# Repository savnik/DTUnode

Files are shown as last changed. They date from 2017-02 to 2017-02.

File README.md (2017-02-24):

DTUnodeMCU
==============

A DTU version of NodeMCU using ESP8285 instead of ESP8266. ESP8285 has built-in flash memory which ESP8266 does not. Besides that the ESP8285 is very much the same.
This will be send to PCB production in March 2017 and tested afterwards.

## Features

- ESP8285, 26 MHz resonator
- Built-in flash memory
- Built-in Wi-Fi
- Onboard PCB Antenna
- Reset and flash button
- Input voltage from 1.3v to 6 volts
- Diode protection for battery and USB power supply
- JST battery connector
- Built-in battery voltage measurement
- RGB Led
- RFM95 LoRaWAN module
- HDC1010 High Accuracy humidity sensor
- VEML6030 High Accuracy Ambient Light Sensor
- MAG3110 Three axis digital magnetometer
- DS3231 Real time clock
- BMP280 Digital pressure sensor
- Pin headers for FTDI, I2C, Chip enable and 2 GPIO's

- - - - - -
Author Peter Savnik
Supervisor Ali Ozkil

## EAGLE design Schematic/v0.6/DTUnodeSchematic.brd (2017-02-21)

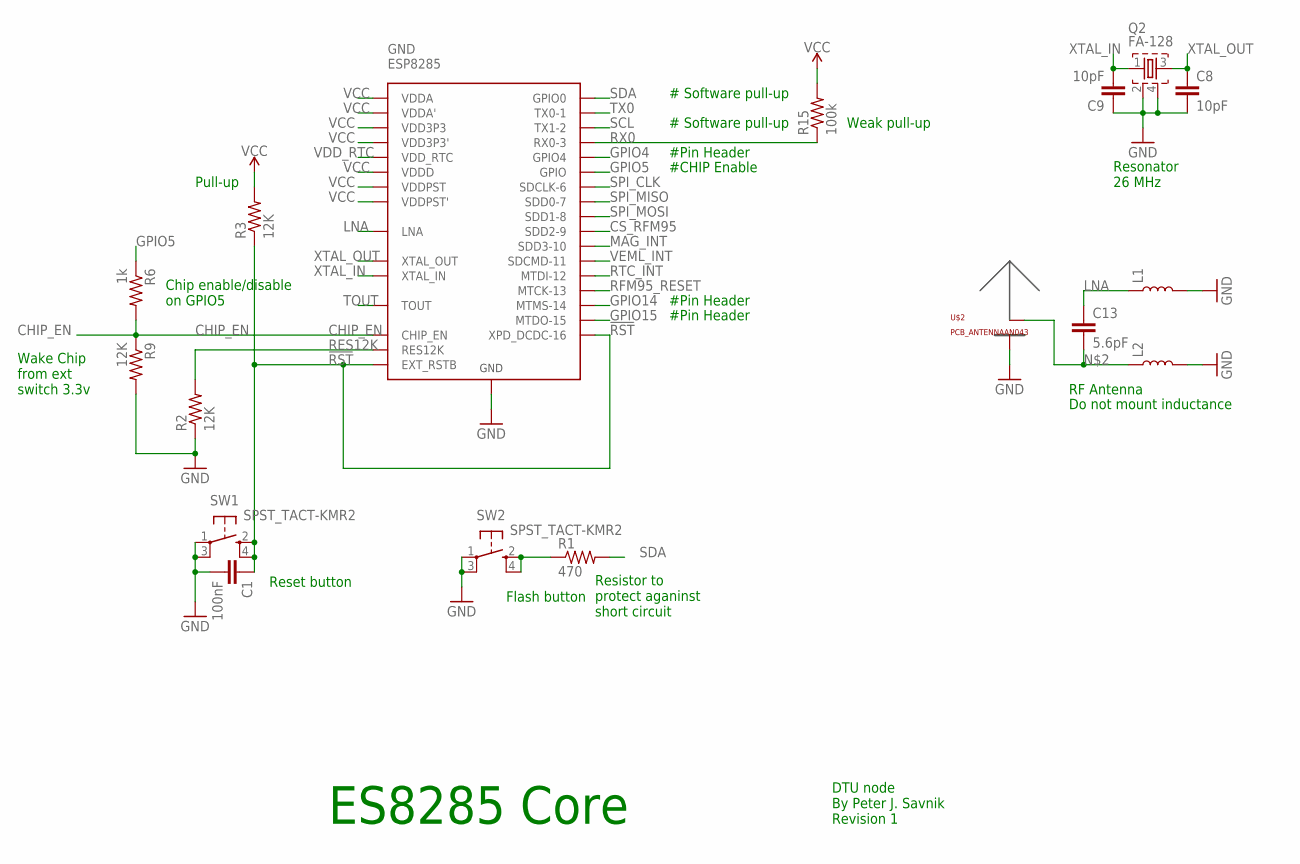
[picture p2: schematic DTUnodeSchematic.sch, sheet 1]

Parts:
C1: 100nF; C0402K
C8, C9: 10pF; C0402K
C13: 5.6pF; C0402K
GND: ESP8285; QFN-32
L1, L2: INDUCTOR-0402-3.9NH; 0402
Q2: FA-128
R1: 470; R0402
R2, R3, R9: 12K; R0402
R6: 1k; R0402
R15: 100k; R0402
SW1, SW2: SPST_TACT-KMR2; KMR2
U$2: PCB_ANTENNAAN043; PCB_ANTENNA_TI-AN043

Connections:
!RST: C1.1, GND.P$8 (XPD_DCDC-16), GND.P$32 (EXT_RSTB), R3.1, SW1.2 (S), SW1.4 (S1); also elsewhere on the board
CHIP_EN: GND.P$7 (CHIP_EN), R6.2, R9.1; also elsewhere on the board
CS_RFM95: GND.P$18 (SDD2-9); also elsewhere on the board
GND: C1.2, C8.2, C9.1, GND.33-GND (GND), L1.2, L2.2, Q2.2, Q2.4, R2.1, R9.2, SW1.1, SW1.3 (P1), SW2.1, SW2.3 (P1), U$2.GND; also elsewhere on the board
GPIO4: GND.P$16 (GPIO4); also elsewhere on the board
GPIO5: GND.P$24 (GPIO), R6.1
GPIO14: GND.P$9 (MTMS-14); also elsewhere on the board
GPIO15: GND.P$13 (MTDO-15); also elsewhere on the board
LNA: C13.1, GND.P$2 (LNA), L1.1
MAG_INT: GND.P$19 (SDD3-10); also elsewhere on the board
unnamed: R1.1, SW2.2 (S), SW2.4 (S1)
unnamed: C13.2, L2.1, U$2.ANT (AND)
RES12K: GND.P$31 (RES12K), R2.2
RFM95_RESET: GND.P$12 (MTCK-13); also elsewhere on the board
RTC_INT: GND.P$10 (MTDI-12); also elsewhere on the board
RX0: GND.P$25 (RX0-3), R15.1; also elsewhere on the board
SCL: GND.P$14 (TX1-2); also elsewhere on the board
SDA: GND.P$15 (GPIO0), R1.2; also elsewhere on the board
SPI_CLK: GND.P$21 (SDCLK-6); also elsewhere on the board
SPI_MISO: GND.P$22 (SDD0-7); also elsewhere on the board
SPI_MOSI: GND.P$23 (SDD1-8); also elsewhere on the board
TOUT: GND.P$6 (TOUT); also elsewhere on the board
TX0: GND.P$26 (TX0-1); also elsewhere on the board
VCC: GND.P$1 (VDDA), GND.P$3 (VDD3P3), GND.P$4 (VDD3P3'), GND.P$11 (VDDPST), GND.P$17 (VDDPST'), GND.P$29 (VDDD), GND.P$30 (VDDA'), R3.2, R15.2; also elsewhere on the board
VDD_RTC: GND.P$5 (VDD_RTC)
VEML_INT: GND.P$20 (SDCMD-11); also elsewhere on the board
XTAL_IN: C9.2, GND.P$28 (XTAL_IN), Q2.1
XTAL_OUT: C8.1, GND.P$27 (XTAL_OUT), Q2.3

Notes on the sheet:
Resonator 26 MHz
Chip enable/disable on GPIO5
RF Antenna
Do not mount inductance
DTU node By Peter J. Savnik Revision 1
ES8285 Core
Reset button
Flash button
Resistor to protect aganinst short circuit
#Pin Header
#CHIP Enable
Wake Chip from ext switch 3.3v
# Software pull-up
Weak pull-up
Pull-up

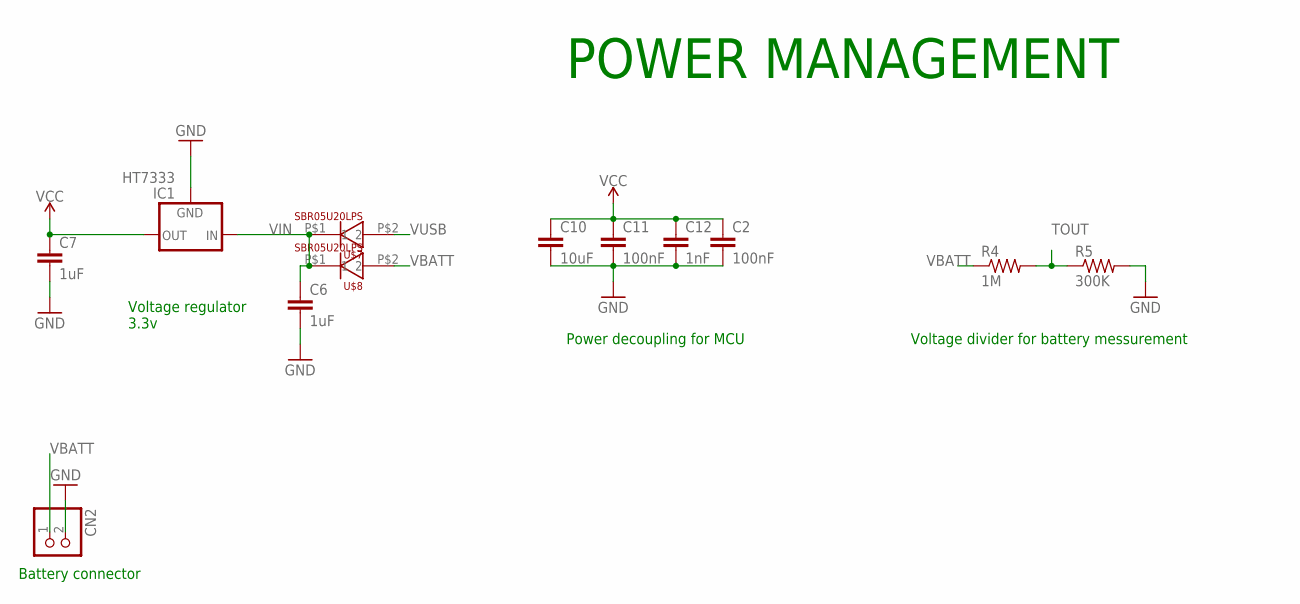
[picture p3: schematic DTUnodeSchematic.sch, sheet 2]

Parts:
C2, C11: 100nF; C0402K
C6, C7: 1uF; C0402K
C10: 10uF; C0402K
C12: 1nF; C0402K
CN2: JST_2PIN-THM-RA; JST-PH-2-THM-RA
IC1: HT7333; SOT-89
R4: 1M; R0402
R5: 300K; R0402
U$7, U$8: SBR05U20LPS; X2-DFN1006-2

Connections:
GND: C2.2, C6.2, C7.2, C10.2, C11.2, C12.2, CN2.2 (1), IC1.2 (GND), R5.2; also elsewhere on the board
TOUT: R4.2, R5.1; also elsewhere on the board
VBATT: CN2.1 (2), R4.1, U$8.P$2 (1); also elsewhere on the board
VCC: C2.1, C7.1, C10.1, C11.1, C12.1, IC1.1 (OUT); also elsewhere on the board
VIN: C6.1, IC1.3 (IN), IC1.4 (IN), U$7.P$1 (2), U$8.P$1 (2)
VUSB: U$7.P$2 (1); also elsewhere on the board

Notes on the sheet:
Voltage regulator 3.3v
POWER MANAGEMENT
Battery connector
Power decoupling for MCU
Voltage divider for battery messurement

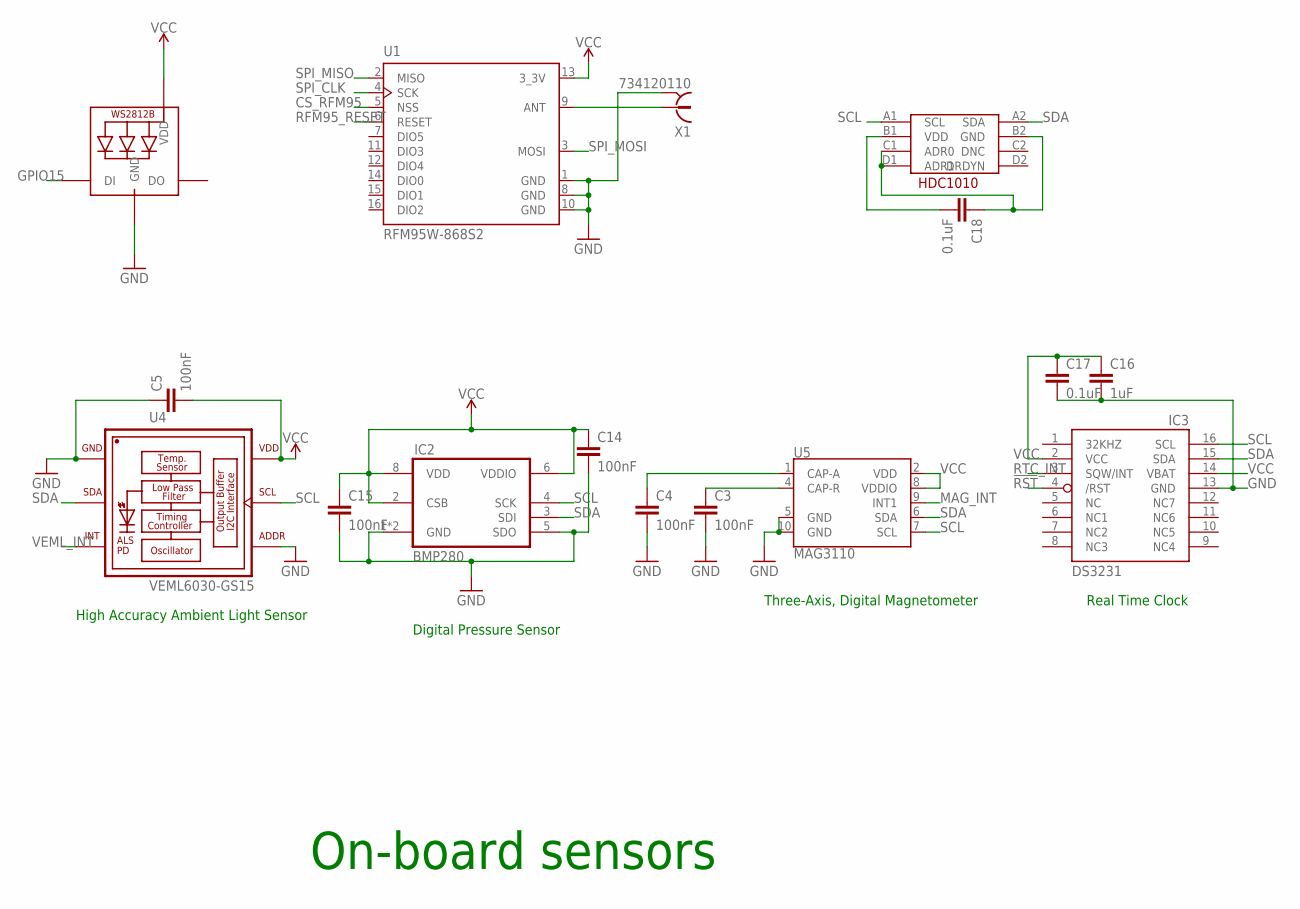
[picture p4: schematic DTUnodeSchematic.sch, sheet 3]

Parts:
C3, C4, C5, C14, C15: 100nF; C0402
C16: 1uF; C0402
C17, C18: 0.1uF; C0402
IC2: BMP280
IC3: DS3231/SO; SO16W
LED1: WS2812B5050; WS2812B
U1: RFM95W-868S2; XCVR_RFM95W-868S2
U4: VEML6030-GS15; VISHAY_VEML6030_2X2X0.87
U5: MAG3110; DFN-10
U$3: HDC1010; DSBGA-8
X1: 734120110

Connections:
!RST: IC3.4 (/RST); also elsewhere on the board
CS_RFM95: U1.5 (NSS); also elsewhere on the board
GND: C3.2, C4.2, C5.1, C14.2, C15.2, C16.2, C17.2, IC2.1 (GND), IC2.5 (SDO), IC2.7 (GND), IC3.13 (GND), LED1.3-GND (GND), U1.1 (GND), U1.8 (GND), U1.10 (GND), U4.1 (GND), U4.4 (ADDR), U5.5 (GND), U5.10 (GND), X1.S@1 (2), X1.S@2 (2), X1.S@3 (2); also elsewhere on the board
GPIO15: LED1.4-DIN (DI); also elsewhere on the board
MAG_INT: U5.9 (INT1); also elsewhere on the board
unnamed: U1.9 (ANT), X1.1
unnamed: C18.2, U$3.B1 (VDD)
unnamed: C18.1, U$3.B2 (GND), U$3.C1 (ADR0), U$3.D1 (ADR1)
unnamed: C3.1, U5.4 (CAP-R)
unnamed: C4.1, U5.1 (CAP-A)
RFM95_RESET: U1.6 (RESET); also elsewhere on the board
RTC_INT: IC3.3 (SQW/INT); also elsewhere on the board
SCL: IC2.4 (SCK), IC3.16 (SCL), U4.5 (SCL), U5.7 (SCL), U$3.A1 (SCL); also elsewhere on the board
SDA: IC2.3 (SDI), IC3.15 (SDA), U4.2 (SDA), U5.6 (SDA), U$3.A2 (SDA); also elsewhere on the board
SPI_CLK: U1.4 (SCK); also elsewhere on the board
SPI_MISO: U1.2 (MISO); also elsewhere on the board
SPI_MOSI: U1.3 (MOSI); also elsewhere on the board
VCC: C5.2, C14.1, C15.1, C16.1, C17.1, IC2.2 (CSB), IC2.6 (VDDIO), IC2.8 (VDD), IC3.2 (VCC), IC3.14 (VBAT), LED1.1-VDD (VDD), U1.13 (3_3V), U4.6 (VDD), U5.2 (VDD), U5.8 (VDDIO); also elsewhere on the board
VEML_INT: U4.3 (INT); also elsewhere on the board

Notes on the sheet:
On-board sensors
High Accuracy Ambient Light Sensor
Digital Pressure Sensor
Real Time Clock
Three-Axis, Digital Magnetometer

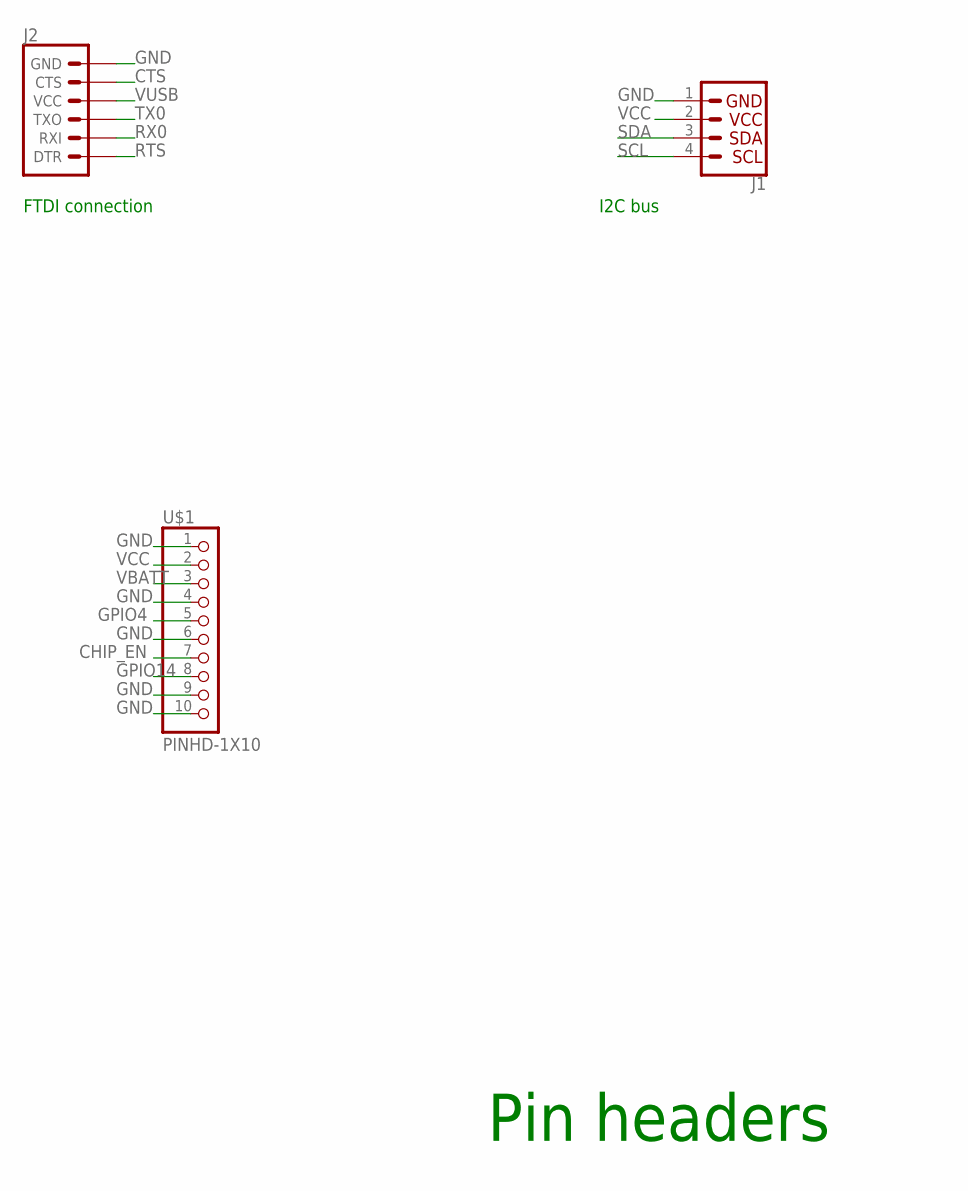
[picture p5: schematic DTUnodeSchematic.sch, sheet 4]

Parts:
J1: I2C_STANDARD; 1X04
J2: 6_PIN_SERIAL_TARGET; 1X06
U$1: PINHD-1X10; 1X10-BIG

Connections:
CHIP_EN: U$1.7; also elsewhere on the board
CTS: J2.5 (CTS)
GND: J1.1, J2.6 (GND), U$1.1, U$1.4, U$1.6, U$1.9, U$1.10; also elsewhere on the board
GPIO4: U$1.5; also elsewhere on the board
GPIO14: U$1.8; also elsewhere on the board
RTS: J2.1 (DTR)
RX0: J2.2 (RXI); also elsewhere on the board
SCL: J1.4; also elsewhere on the board
SDA: J1.3; also elsewhere on the board
TX0: J2.3 (TXO); also elsewhere on the board
VBATT: U$1.3; also elsewhere on the board
VCC: J1.2, U$1.2; also elsewhere on the board
VUSB: J2.4 (VCC); also elsewhere on the board

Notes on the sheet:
FTDI connection
Pin headers
I2C bus

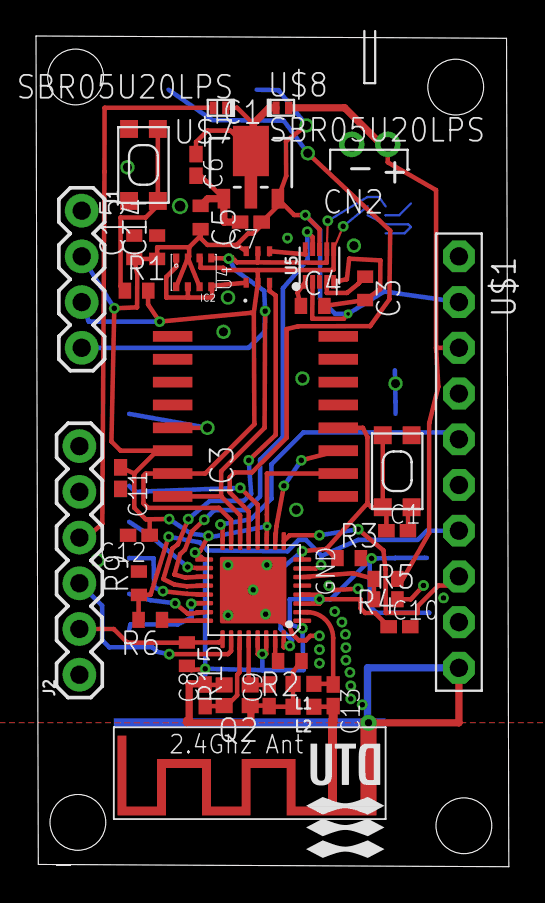
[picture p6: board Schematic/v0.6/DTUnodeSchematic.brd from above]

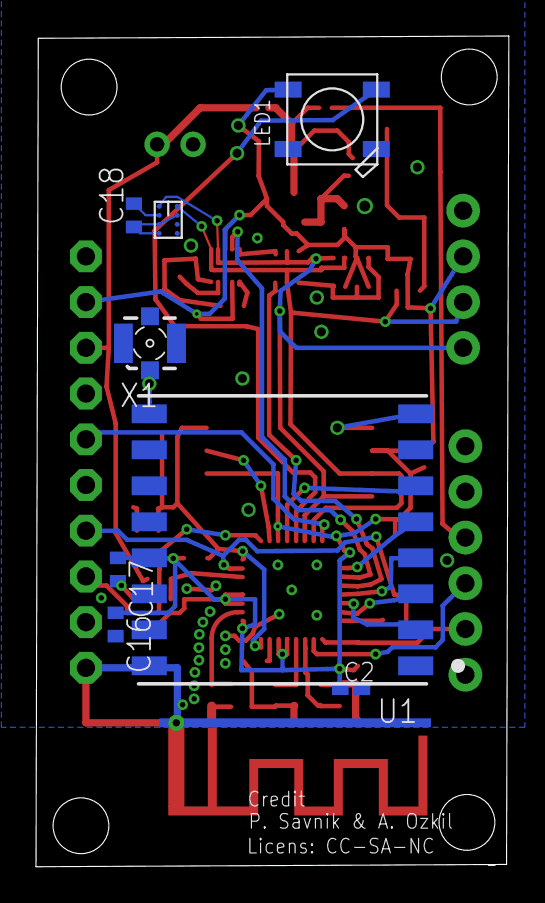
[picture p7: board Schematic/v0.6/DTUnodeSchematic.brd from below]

Board: 2 copper layers, 26.3 x 46.2 mm, 48 parts (8 on the bottom side), 35 nets.

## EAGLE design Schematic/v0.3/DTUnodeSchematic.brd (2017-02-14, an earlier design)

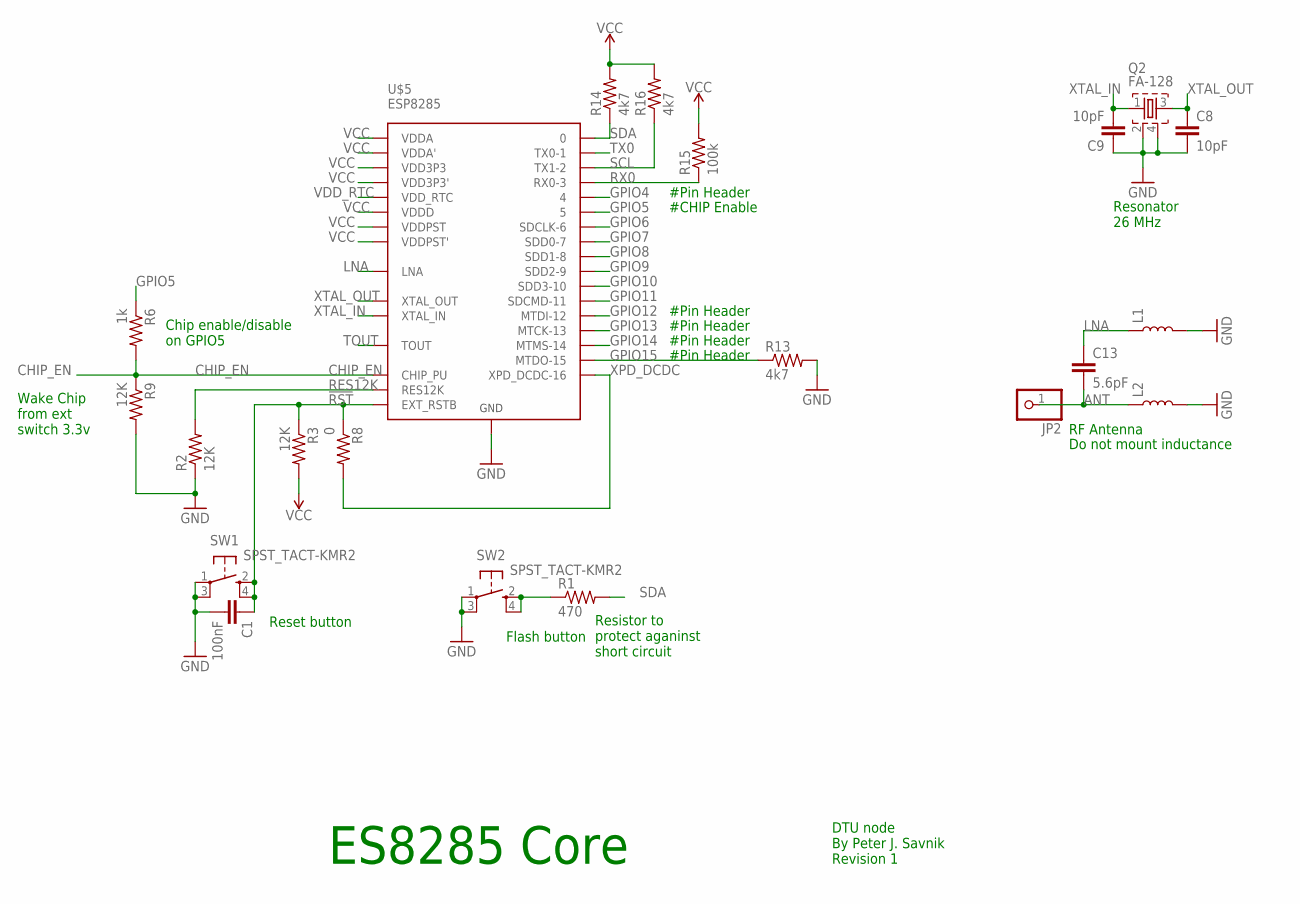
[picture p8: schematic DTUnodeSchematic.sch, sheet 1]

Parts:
C1: 100nF; C0402K
C8, C9: 10pF; C0402K
C13: 5.6pF; C0402K
JP2: PINHD-1X1; 1X01
L1, L2: INDUCTOR-0402-3.9NH; 0402
Q2: FA-128
R1: 470; R0402
R2, R3, R9: 12K; R0402
R6: 1k; R0402
R8: 0; R0402
R13, R14, R16: 4k7; R0402
R15: 100k; R0402
SW1, SW2: SPST_TACT-KMR2; KMR2
U$5: ESP8285; QFN-32

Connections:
!RST: C1.1, R3.1, R8.1, SW1.2 (S), SW1.4 (S1), U$5.P$32 (EXT_RSTB)
ANT: C13.2, JP2.1, L2.1
CHIP_EN: R6.2, R9.1, U$5.P$7 (CHIP_PU); also elsewhere on the board
GND: C1.2, C8.2, C9.1, L1.2, L2.2, Q2.2, Q2.4, R2.1, R9.2, R13.2, SW1.1, SW1.3 (P1), SW2.1, SW2.3 (P1), U$5.33-GND (GND); also elsewhere on the board
GPIO4: U$5.P$16 (4); also elsewhere on the board
GPIO5: R6.1, U$5.P$24 (5)
GPIO6: U$5.P$21 (SDCLK-6)
GPIO7: U$5.P$22 (SDD0-7)
GPIO8: U$5.P$23 (SDD1-8)
GPIO9: U$5.P$18 (SDD2-9)
GPIO10: U$5.P$19 (SDD3-10)
GPIO11: U$5.P$20 (SDCMD-11)
GPIO12: U$5.P$10 (MTDI-12); also elsewhere on the board
GPIO13: U$5.P$12 (MTCK-13); also elsewhere on the board
GPIO14: U$5.P$9 (MTMS-14); also elsewhere on the board
GPIO15: R13.1, U$5.P$13 (MTDO-15); also elsewhere on the board
LNA: C13.1, L1.1, U$5.P$2 (LNA)
unnamed: R1.1, SW2.2 (S), SW2.4 (S1)
RES12K: R2.2, U$5.P$31 (RES12K)
RX0: R15.1, U$5.P$25 (RX0-3); also elsewhere on the board
SCL: R16.1, U$5.P$14 (TX1-2); also elsewhere on the board
SDA: R1.2, R14.1, U$5.P$15 (0); also elsewhere on the board
TOUT: U$5.P$6 (TOUT); also elsewhere on the board
TX0: U$5.P$26 (TX0-1); also elsewhere on the board
VCC: R3.2, R14.2, R15.2, R16.2, U$5.P$1 (VDDA), U$5.P$3 (VDD3P3), U$5.P$4 (VDD3P3'), U$5.P$11 (VDDPST), U$5.P$17 (VDDPST'), U$5.P$29 (VDDD), U$5.P$30 (VDDA'); also elsewhere on the board
VDD_RTC: U$5.P$5 (VDD_RTC)
XPD_DCDC: R8.2, U$5.P$8 (XPD_DCDC-16)
XTAL_IN: C9.2, Q2.1, U$5.P$28 (XTAL_IN)
XTAL_OUT: C8.1, Q2.3, U$5.P$27 (XTAL_OUT)

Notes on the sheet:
Resonator 26 MHz
Chip enable/disable on GPIO5
RF Antenna
Do not mount inductance
DTU node By Peter J. Savnik Revision 1
ES8285 Core
Reset button
Flash button
Resistor to protect aganinst short circuit
#Pin Header
#CHIP Enable
Wake Chip from ext switch 3.3v

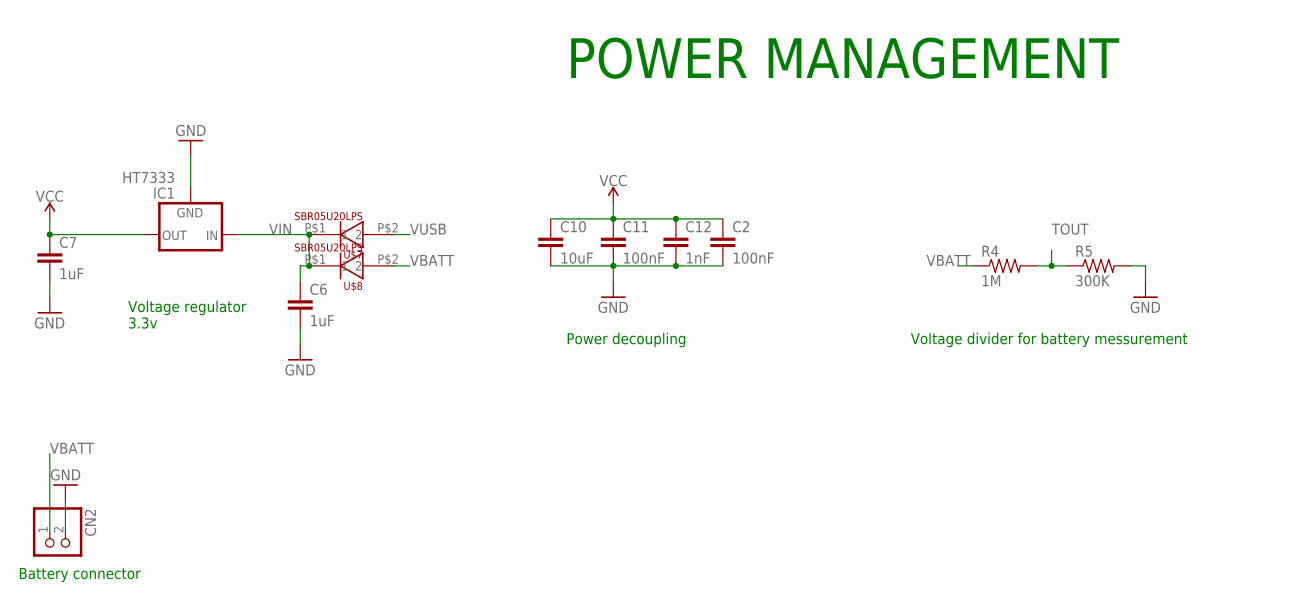
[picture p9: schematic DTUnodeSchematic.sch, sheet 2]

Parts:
C2, C11: 100nF; C0402K
C6, C7: 1uF; C0402K
C10: 10uF; C0402K
C12: 1nF; C0402K
CN2: JST_2PIN-THM-RA; JST-PH-2-THM-RA
IC1: HT7333; SOT-89
R4: 1M; R0402
R5: 300K; R0402
U$7, U$8: SBR05U20LPS; X2-DFN1006-2

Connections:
GND: C2.2, C6.2, C7.2, C10.2, C11.2, C12.2, CN2.2 (1), IC1.2 (GND), R5.2; also elsewhere on the board
TOUT: R4.2, R5.1; also elsewhere on the board
VBATT: CN2.1 (2), R4.1, U$8.P$2 (1); also elsewhere on the board
VCC: C2.1, C7.1, C10.1, C11.1, C12.1, IC1.1 (OUT); also elsewhere on the board
VIN: C6.1, IC1.3 (IN), IC1.4 (IN), U$7.P$1 (2), U$8.P$1 (2)
VUSB: U$7.P$2 (1); also elsewhere on the board

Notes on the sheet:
Voltage regulator 3.3v
POWER MANAGEMENT
Battery connector
Power decoupling
Voltage divider for battery messurement

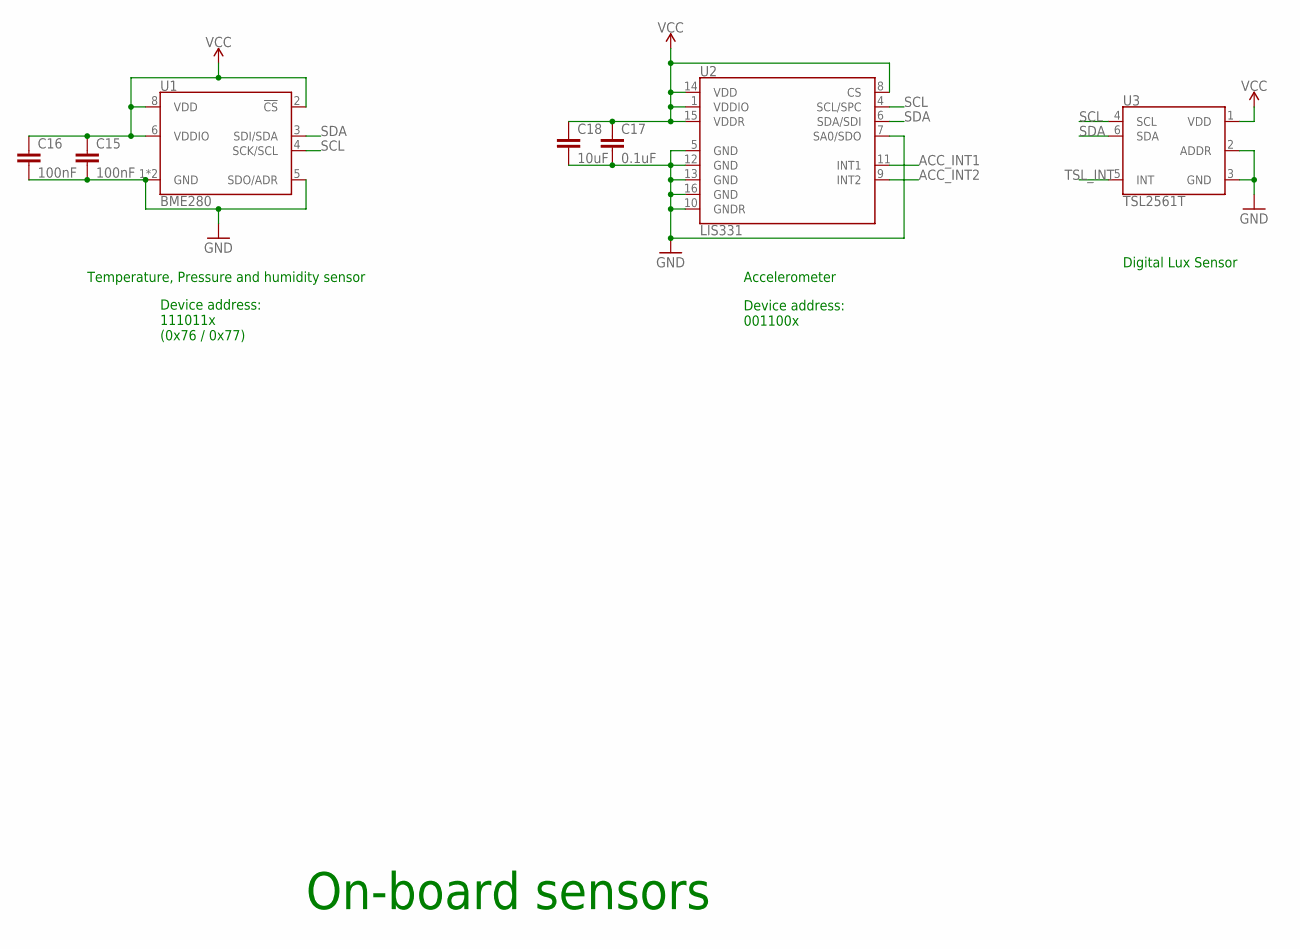
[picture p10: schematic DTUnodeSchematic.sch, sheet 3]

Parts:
C15, C16: 100nF; C0402
C17: 0.1uF; C0402
C18: 10uF; C0402
U1: BME280; LGA-8-2.5X2.5
U2: LIS331; LGA-16-3X3
U3: TSL2561T; TMB-6

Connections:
ACC_INT1: U2.11 (INT1)
ACC_INT2: U2.9 (INT2)
GND: C15.2, C16.2, C17.2, C18.2, U1.1 (GND), U1.5 (SDO/ADR), U1.7 (GND), U2.5 (GND), U2.7 (SA0/SDO), U2.10 (GNDR), U2.12 (GND), U2.13 (GND), U2.16 (GND), U3.2 (ADDR), U3.3 (GND); also elsewhere on the board
SCL: U1.4 (SCK/SCL), U2.4 (SCL/SPC), U3.4 (SCL); also elsewhere on the board
SDA: U1.3 (SDI/SDA), U2.6 (SDA/SDI), U3.6 (SDA); also elsewhere on the board
TSL_INT: U3.5 (INT)
VCC: C15.1, C16.1, C17.1, C18.1, U1.2 (!CS), U1.6 (VDDIO), U1.8 (VDD), U2.1 (VDDIO), U2.8 (CS), U2.14 (VDD), U2.15 (VDDR), U3.1 (VDD); also elsewhere on the board

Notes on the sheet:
Temperature, Pressure and humidity sensor
Device address: 111011x (0x76 / 0x77)
Device address: 001100x
Accelerometer
Digital Lux Sensor
On-board sensors

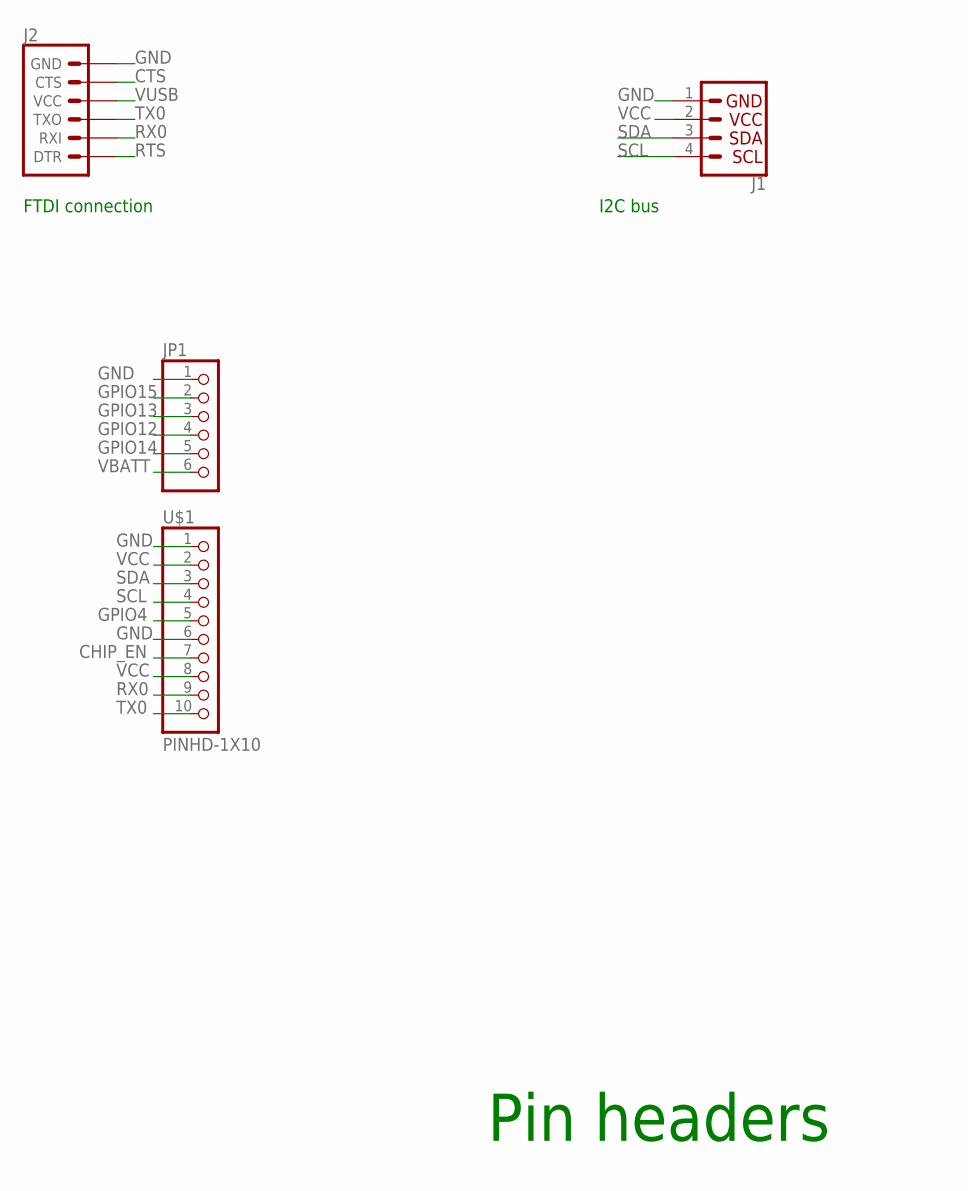
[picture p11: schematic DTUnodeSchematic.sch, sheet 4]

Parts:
J1: I2C_STANDARD; 1X04
J2: 6_PIN_SERIAL_TARGET; 1X06
JP1: PINHD-1X6; 1X06
U$1: PINHD-1X10; 1X10-BIG

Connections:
CHIP_EN: U$1.7; also elsewhere on the board
CTS: J2.5 (CTS)
GND: J1.1, J2.6 (GND), JP1.1, U$1.1, U$1.6; also elsewhere on the board
GPIO4: U$1.5; also elsewhere on the board
GPIO12: JP1.4; also elsewhere on the board
GPIO13: JP1.3; also elsewhere on the board
GPIO14: JP1.5; also elsewhere on the board
GPIO15: JP1.2; also elsewhere on the board
RTS: J2.1 (DTR)
RX0: J2.2 (RXI), U$1.9; also elsewhere on the board
SCL: J1.4, U$1.4; also elsewhere on the board
SDA: J1.3, U$1.3; also elsewhere on the board
TX0: J2.3 (TXO), U$1.10; also elsewhere on the board
VBATT: JP1.6; also elsewhere on the board
VCC: J1.2, U$1.2, U$1.8; also elsewhere on the board
VUSB: J2.4 (VCC); also elsewhere on the board

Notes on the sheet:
FTDI connection
Pin headers
I2C bus

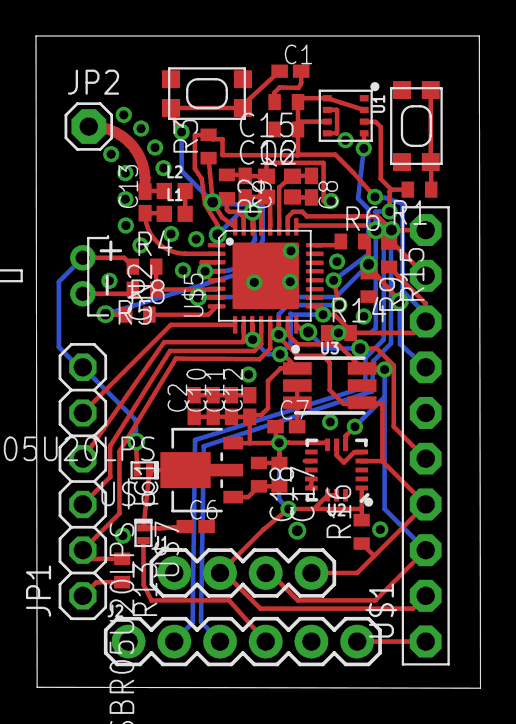
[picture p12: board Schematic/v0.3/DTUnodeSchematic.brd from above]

Board: 2 copper layers, 24.7 x 36.2 mm, 44 parts (0 on the bottom side), 25 nets.

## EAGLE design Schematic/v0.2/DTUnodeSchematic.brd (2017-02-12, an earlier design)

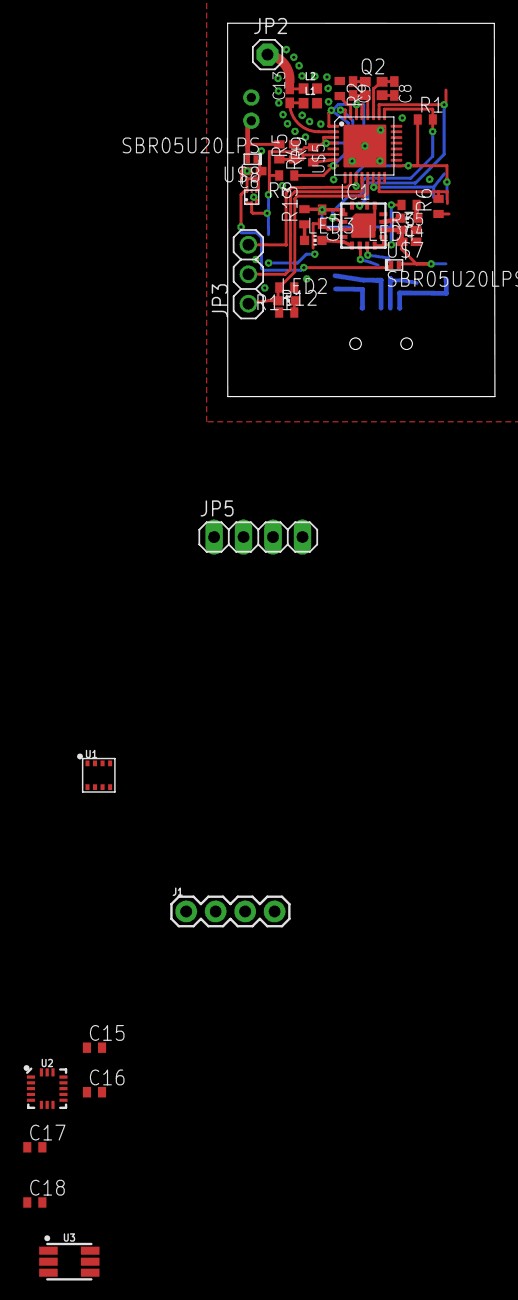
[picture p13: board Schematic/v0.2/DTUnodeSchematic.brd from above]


Board: 2 copper layers, 23.0 x 32.2 mm, 54 parts (14 on the bottom side), 32 nets.

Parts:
C1: 10nF; C0402K
C2, C3: 47pF; C0402K
C4: 4.7uF; C0402K
C5, C11, C14: 100nF; C0402K
C6, C7: 1uF; C0402K
C8, C9: 10pF; C0402K
C10: 10uF; C0402K
C12: 1nF; C0402K
C13: 5.6pF; C0402K
C15, C16: 100nF; C0402
C17: 0.1uF; C0402
C18: 10uF; C0402
CN1: USB-MINIB
CN2: JST-PH-2-THM-RA
IC1: FT230XQ; QFN16
J1: 1X04
JP2: 1X01
JP3: 1X03
JP5: 1X04
L1, L2: 0402
L3, L4: BLM15HB121SN1; 0402
LED2, LED3: blue; CHIP-LED0603
LED4: red; CHIP-LED0603
Q2: FA-128
R1: 100K; R0402
R2, R8, R9: 12K; R0402
R3, R12, R13: 1k; R0402
R4: 1M; R0402
R5: 300K; R0402
R6, R7: 4K7; R0402
R11: 4k7; R0402
R14, R15: 27; R0402
U1: BME280; LGA-8-2.5X2.5
U2: LIS331; LGA-16-3X3
U3: TSL2561T; TMB-6
U$5: ESP8285; QFN-32
U$6: MIC5528; 6-PIN_1.2MMX1.2MM_THIN_FDN(MT)
U$7, U$8: SBR05U20LPS; X2-DFN1006-2

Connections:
!RST: R8.1, U$5.P$8, U$5.P$32
ANT: C13.2, JP2.1, L2.1
BATT: CN2.1, R4.1, U$8.P$2
CHIP_EN: R9.1, U$5.P$7
GND: C1.2, C2.2, C3.2, C4.2, C5.2, C6.2, C7.2, C8.2, C9.1, C10.2, C11.2, C12.2, C14.2, C15.2, C16.2, C17.2, C18.2, CN2.2, IC1.3, IC1.13, J1.1, JP5.4, L1.2, L2.2, L3.1, Q2.2, Q2.4, R2.1, R5.2, R11.1, R12.1, U1.1, U1.5, U1.7, U2.5, U2.7, U2.10, U2.12, U2.13, U2.16, U3.2, U3.3, U$5.33-GND, U$6.P$3
LNA: C13.1, L1.1, U$5.P$2
MTCK: JP3.2, U$5.P$12
MTDI: JP3.3, U$5.P$10
MTDO: JP3.1, LED2.A, R11.2, U$5.P$13
unnamed: CN1.GND, L3.2
unnamed: IC1.6, R14.1
unnamed: C1.1, CN1.VBUS, L4.2
unnamed: C2.1, CN1.D+, R14.2
unnamed: C3.1, CN1.D-, R15.2
unnamed: LED2.C, R12.2
unnamed: IC1.7, R15.1
unnamed: LED3.A, R13.1
unnamed: LED4.A, R3.1
unnamed: IC1.5, LED3.C
unnamed: IC1.11, LED4.C
RES12K: R2.2, U$5.P$31
RX0: IC1.2, R1.2, U$5.P$25
SCL: J1.4, R7.2, U1.4, U2.4, U3.4, U$5.P$14
SDA: J1.3, R6.2, U1.3, U2.6, U3.6, U$5.P$15
TOUT: R4.2, R5.1, U$5.P$6
TX0: IC1.15, JP5.2, U$5.P$26
VCC: C7.1, C10.1, C11.1, C12.1, C15.1, C16.1, C17.1, C18.1, J1.2, JP5.3, R1.1, R6.1, R7.1, R8.2, R9.2, U1.2, U1.6, U1.8, U2.1, U2.8, U2.14, U2.15, U3.1, U$5.P$1, U$5.P$3, U$5.P$4, U$5.P$11, U$5.P$17, U$5.P$29, U$5.P$30, U$6.P$1, U$6.P$2
VCCIO: C14.1, IC1.1, IC1.8, IC1.9, R3.2, R13.2
VIN: C6.1, U$6.P$4, U$6.P$6, U$7.P$1, U$8.P$1
VUSB: C4.1, C5.1, IC1.10, L4.1, U$7.P$2
XTAL_IN: C9.2, Q2.1, U$5.P$28
XTAL_OUT: C8.1, Q2.3, U$5.P$27

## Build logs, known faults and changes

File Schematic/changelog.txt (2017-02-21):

v0.1: Initial board layout - basic
v0.2: Added a few sensorts
v0.3: ESP8285 with flash + boot button, BME280 sensor, LIS331, TLS251T, benyt ch_pd for wake up
v0.4: Fjern: FTDI og BME280, 
	tilføj: FTDI pins, lora module rfm95, bmp280, hdc1010
	Der er internal pull-up/down på alle GPIO pins dermed fjernes pull-up/down fra GPIO pins. 
v0.5: Decoupling caps for all components, LED 5050 1655, HDC1010, Silkscreen logo, M3 mount holes.

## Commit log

2017-02-09 Version 0.1
    Basic Sketch. Needs improvements on:
    low leakage Ldo/boost such as ht7333
    Remove the USB serial chip - it uses too much current. headers for Rx
    tx gnd 3.3v instead.
    Remove the power led - it will kill the battery.
    Some onboard sensors / at least footprint for those : bme280, an
    accelerometer, maybe a lux sensor. An extra i2c header for i2c oled
    screens...
    [DTUnodeSchematic.brd, DTUnodeSchematic.sch]
2017-02-12 v0.2 added sensors
    [DTUnodeSchematic.brd, DTUnodeSchematic.sch]
2017-02-14 Version 0.3 ESP8285 with flash + boot button, BME280 sensor, LIS331, TLS251T
    next version:
    tilføj: FTDI pins, lora module rfm95, bmp280, hdc1010
2017-02-20 Dev of v. 0.5 start
    [DTUnodeSchematic.brd, DTUnodeSchematic.sch]
2017-02-21 v0.5
    Decoupling caps for all components, LED 5050 1655, HDC1010, Silkscreen
    logo, M3 mount holes.
    [DTUnodeSchematic.brd, DTUnodeSchematic.sch]
2017-02-21 v0.6
    Reduced vias to 0.3mm
    Found a short circuit
    0.5mm hole for ext antenna (Lora)
    [DTUnodeSchematic.brd, DTUnodeSchematic.sch]

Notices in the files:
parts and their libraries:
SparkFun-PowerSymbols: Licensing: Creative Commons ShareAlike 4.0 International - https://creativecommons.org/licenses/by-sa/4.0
